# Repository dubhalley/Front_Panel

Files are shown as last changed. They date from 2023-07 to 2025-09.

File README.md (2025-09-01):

# Front_Panel

**Here an example of a design on Inkscape**

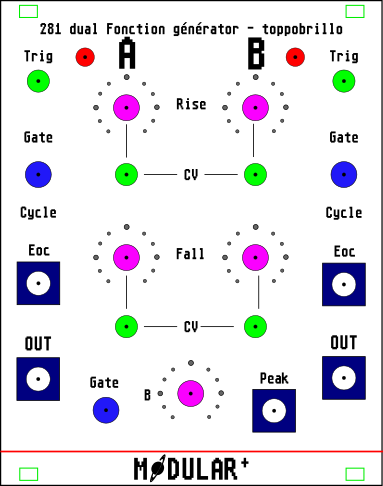
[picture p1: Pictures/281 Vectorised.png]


**Here the result after laserCutting and coloring fonts with white paint**

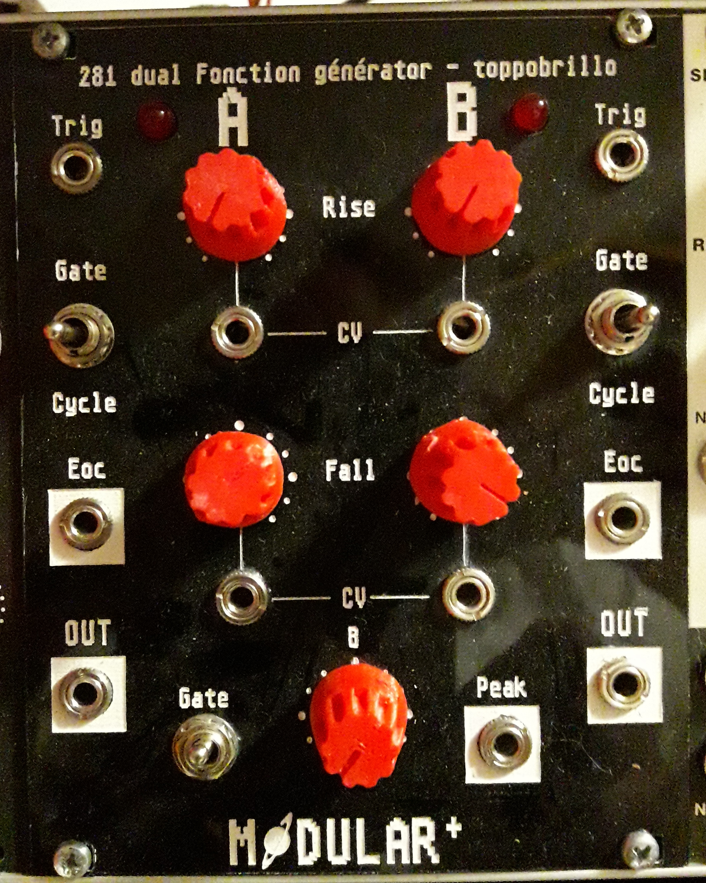
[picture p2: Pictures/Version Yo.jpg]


## 1 - Design software

**FREECAD**

Freecad is a free 2D and 3D drawing software. : https://www.freecad.org/
It allowed me to draw the module's outer contour and fixing holes.

Then I insert it into Inkscape to add images and texts.
But, why don't I use Inkscape at the beginning for the module's outer contour and fixing holes ?

Quite simply because Freecad lets me set dimensional constraints.
The outside size can be defined very precisely, and the fixing holes can be placed at an exact distance from the edge.
And, even if I change the outside dimension, the position and size of the fixing holes will remain the same.

I made files with the current front panel sizes

You will find them in the 2D files folder.

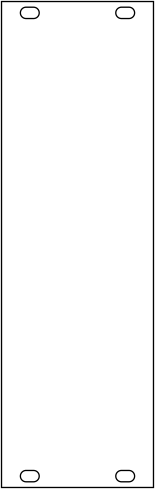
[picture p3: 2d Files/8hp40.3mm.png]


**INKSCAPE**

Inkscape is a free 2D vectoriel drawing software. https://inkscape.org/
In Inkscape you can create a 2D vector design with easy and pretty image and text insertion with also some tool to align holes of defined diameters for knob, switch, jacks, leds ... 
You can play with fonts, pictures and much more... :)

Here one of my design, you'll find the .svg on 2D files folder

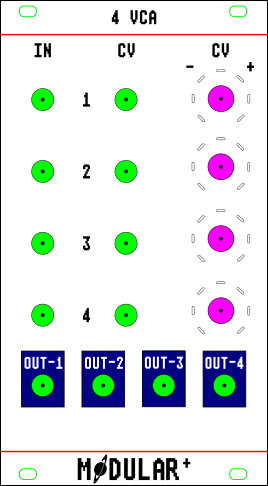
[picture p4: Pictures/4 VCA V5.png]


There is also my generic page with all the necessary components (Jacks, Pots, switchs...)

You'll find them in .svg format the 2D files folder.

**KICAD**

Kicad is a free creating pcb software. https://www.kicad.org/
It is common to obtain front panels using this software.

You have to insert the svg file in Kicad, and define each drawing or writing on a layer of the PCB.

I wanted to make a documentation, but during my reading, I found some resources on synth front panel manufacturing that make me think I probably couldn't do better... :)

https://arx.wtf/blog/1-front-panels-tips

https://www.youtube.com/watch?v=m__D1doHVVk

## 2 - Fabrication

To obtain the next front panels you'll need a lasercutter. Like 3d printer you can find it in a fablab.

**Lasercut PMMA**

An example of lasercutted Pmma or plexiglas



1 - Rendering after laser cutting

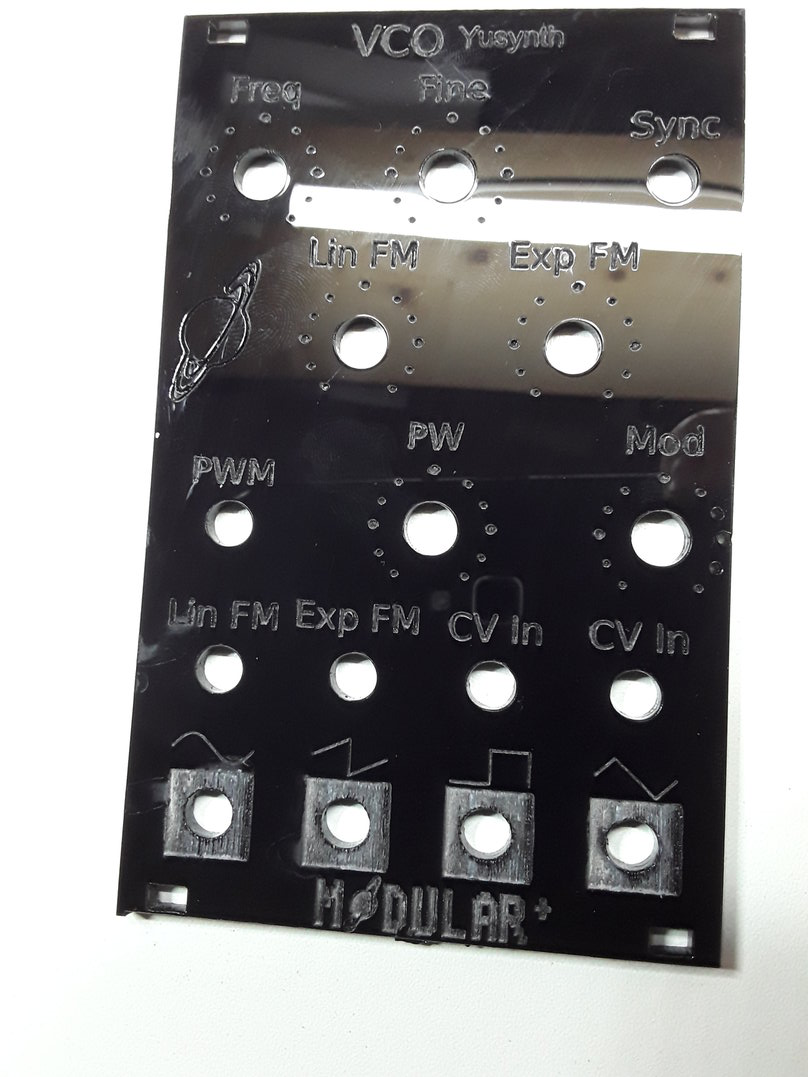
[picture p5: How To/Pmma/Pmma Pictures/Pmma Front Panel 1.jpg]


2 - Paint for inking writings and drawings

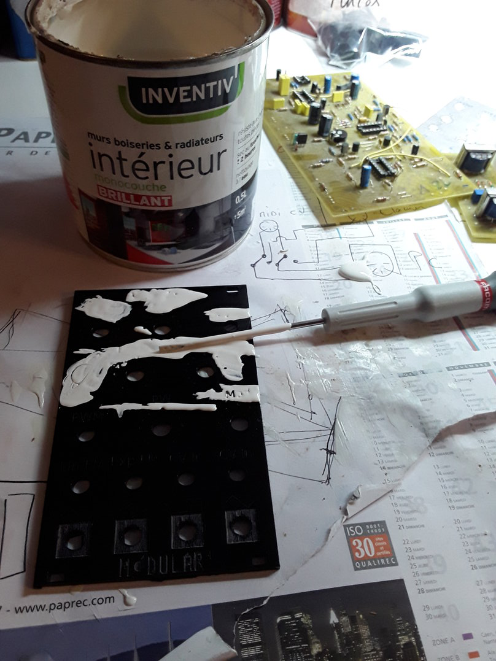
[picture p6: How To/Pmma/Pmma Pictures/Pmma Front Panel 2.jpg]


3 - A tiling scraper to spread it all out so that it fits into the grooves.

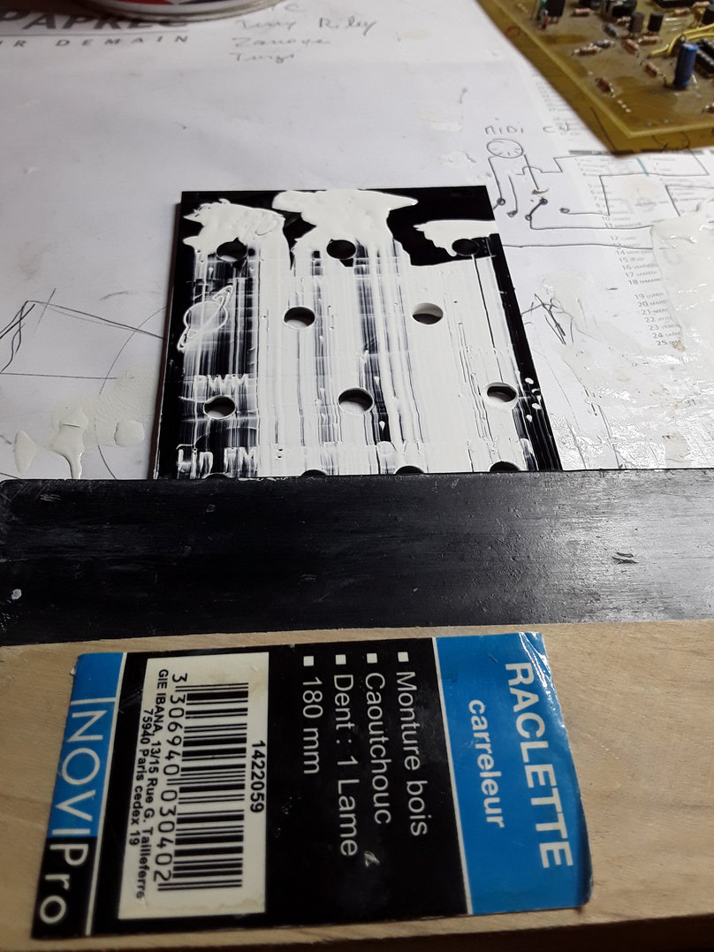
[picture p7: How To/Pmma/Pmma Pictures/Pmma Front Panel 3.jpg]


4 - Leave to dry

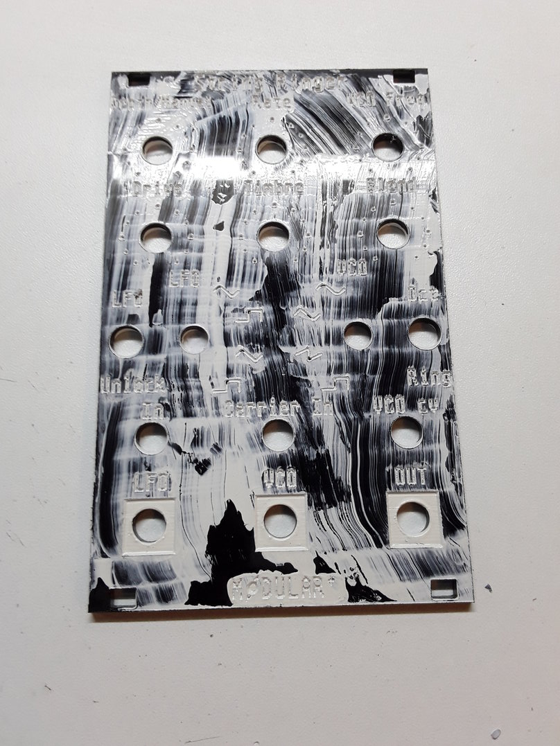
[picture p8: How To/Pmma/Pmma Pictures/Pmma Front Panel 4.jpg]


5 - Take a wet cloth and rub to remove any paint that's not in the right place.

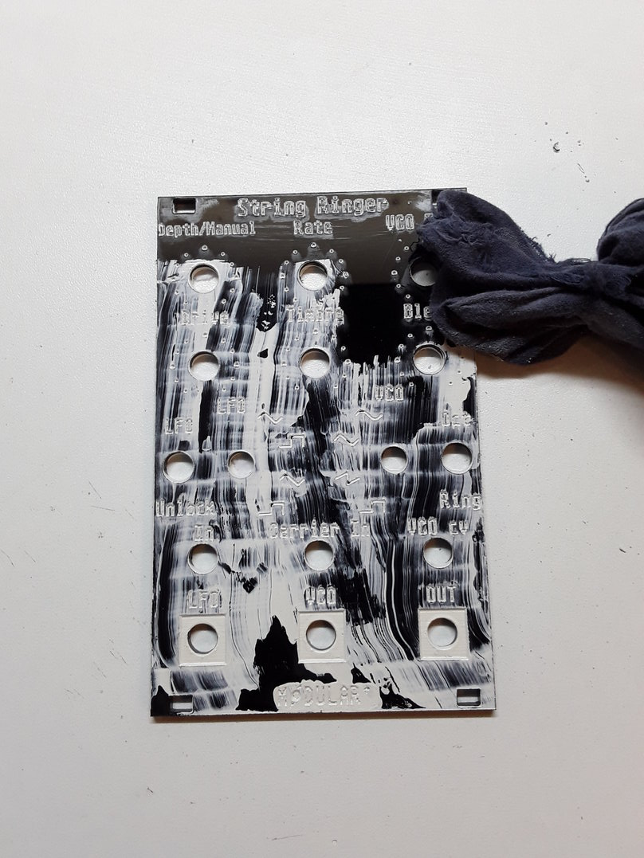
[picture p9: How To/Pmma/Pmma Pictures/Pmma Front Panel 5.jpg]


6 - Here's how it looks, when it's all finished (I'm not very fussy) we can do better ...

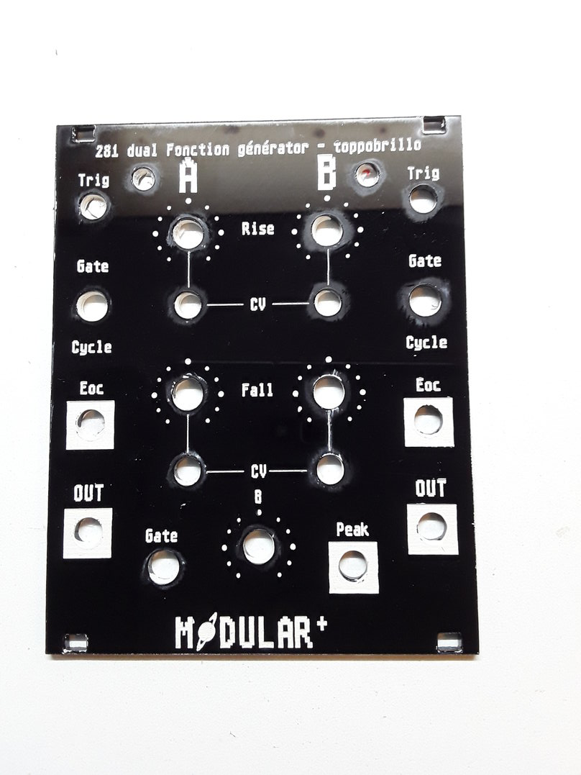
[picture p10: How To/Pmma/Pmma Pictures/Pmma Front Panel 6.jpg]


7 - The front panel with parts

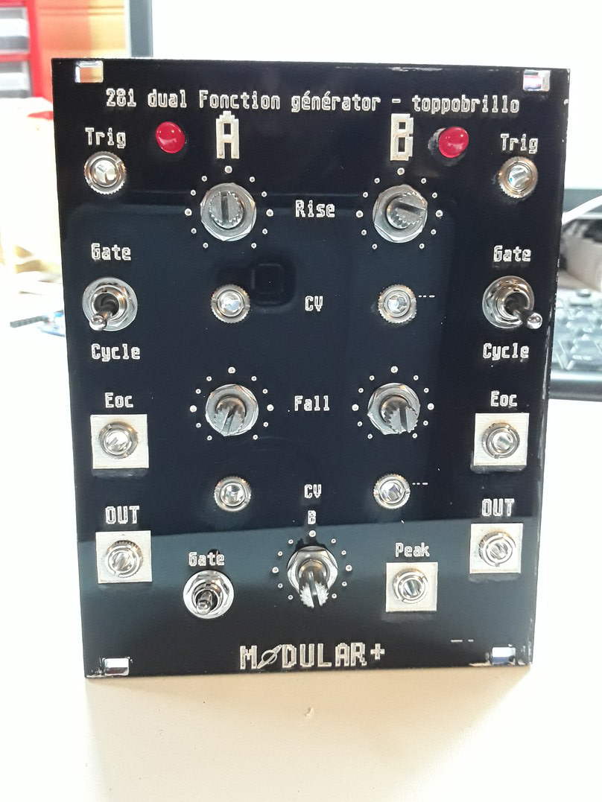
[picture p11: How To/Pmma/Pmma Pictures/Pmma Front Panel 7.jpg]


8 - It's all over

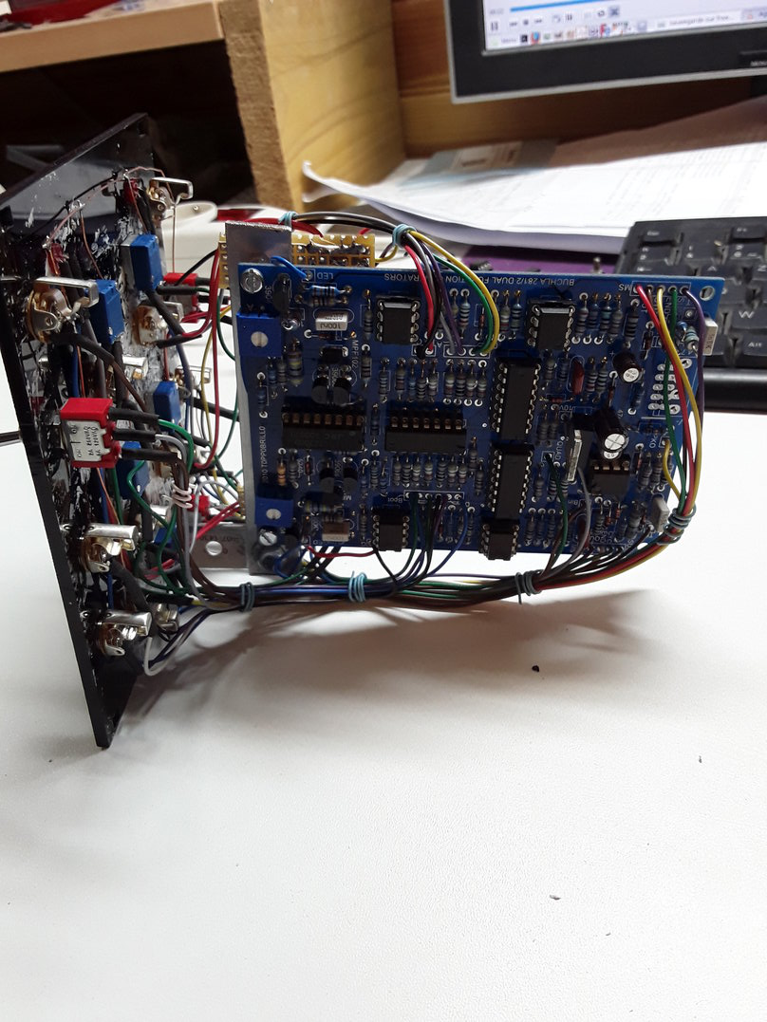
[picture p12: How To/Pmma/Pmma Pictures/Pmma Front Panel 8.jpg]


**Lasercut WOOD**

Poplar plywood 3mm

There's less work after cutting for poplar plywood, as the engraving provides enough contrast to distinguish the writing and images.



**Lasergraving Dibond**

3mm dibond = Dibond® is an aluminum composite material (ACM). It is comprised of two pre-painted sheets of . 012″ (. 30mm) aluminum with a solid polyethylene core.

Most easy-to-find machines cannot engrave in aluminum.
But aluminum is painted, so engraving works in place of cutting.
However, you'll need to drill the holes with a drill press and cut the edge precisely.
But it's functional, quite pretty, and inexpensive, as sports clubs use this material for their advertising.
As their sponsors change, they no longer use the old panels...
On one side there's the advertising, on the other it's blank, ready to engrave, sometimes even with the protective layer still on :)



1 - Open your design in lightburn or other software to control the laser cutter, and choose what will be filled in (as if coloring the inside of a drawing) and what will be marked (as if drawing just the outline of the drawing).



2 - Engraving

I'm using an Atomstack X20 Pro



3 - Cleaning the engraving

To clean, I use toothpaste and a toothbrush, because it sands nicely without scratching too much.

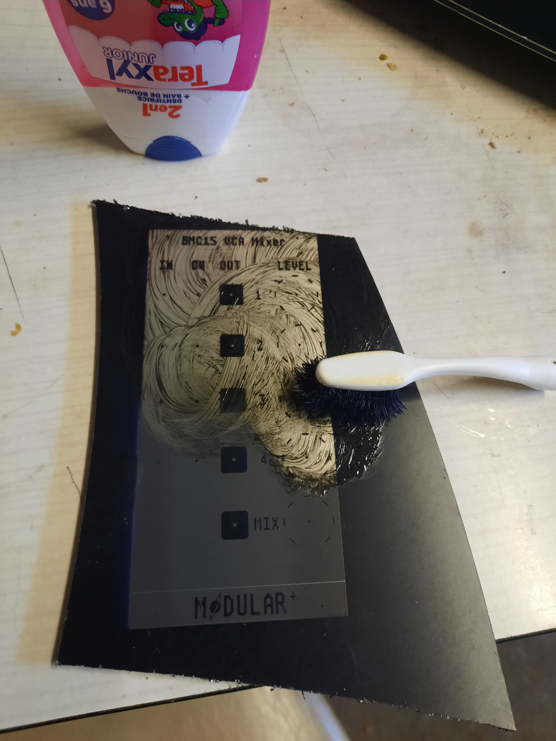
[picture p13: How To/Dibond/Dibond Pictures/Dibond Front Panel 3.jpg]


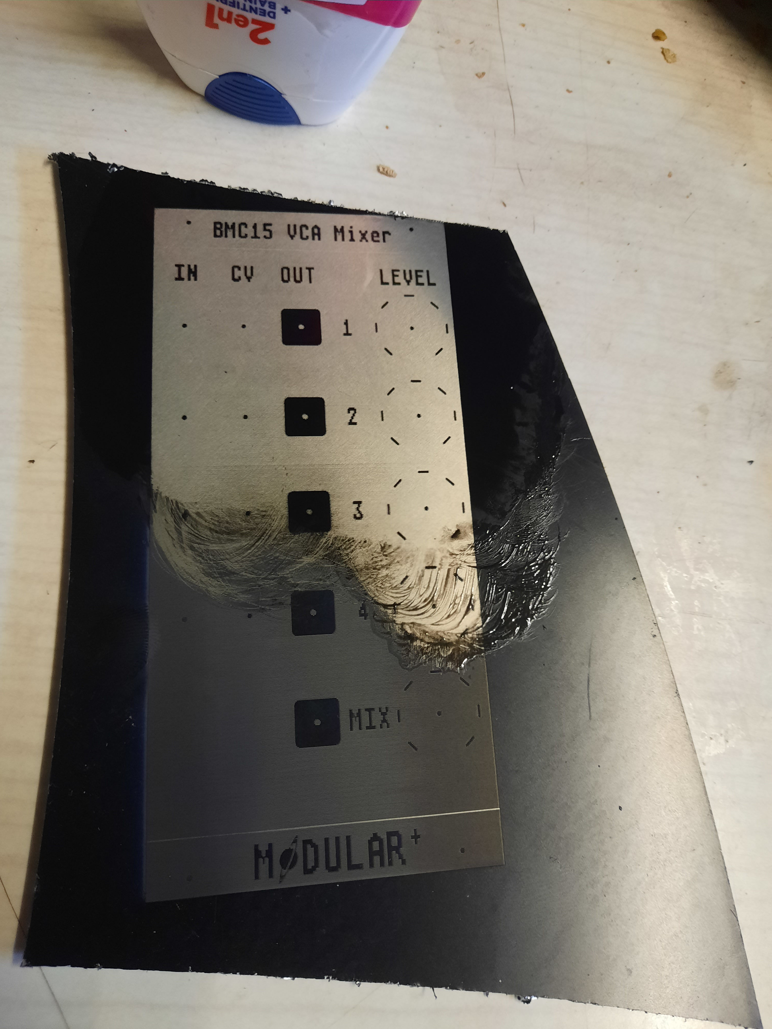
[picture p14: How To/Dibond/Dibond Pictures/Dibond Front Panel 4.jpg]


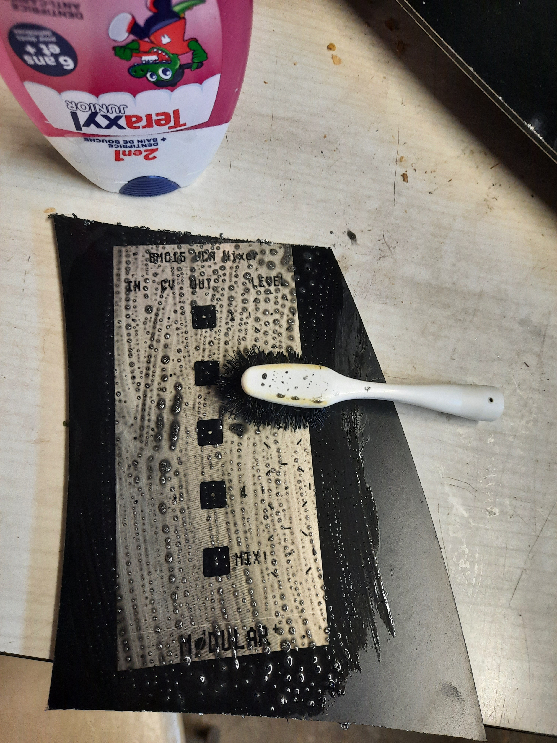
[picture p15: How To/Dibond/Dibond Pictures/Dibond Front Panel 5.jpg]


4 - Cut and file the edges

To cut the edges, I use a wooden wedge to guide the hacksaw blade.

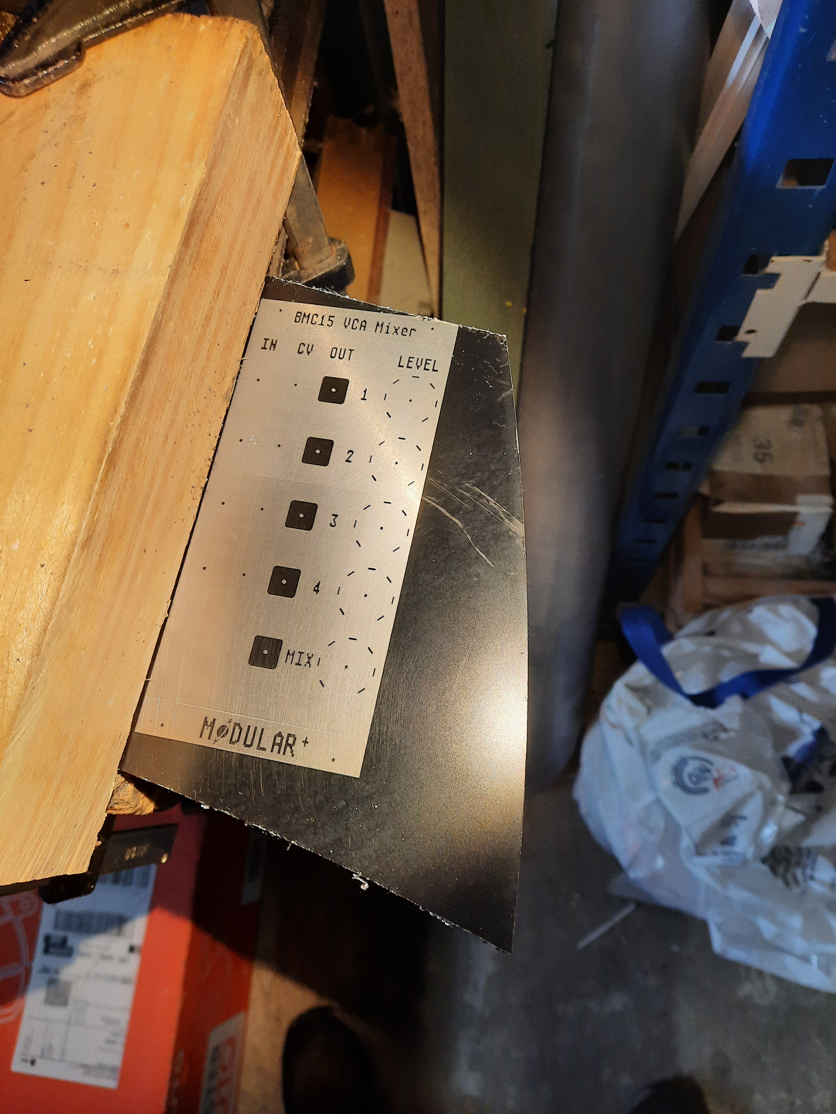
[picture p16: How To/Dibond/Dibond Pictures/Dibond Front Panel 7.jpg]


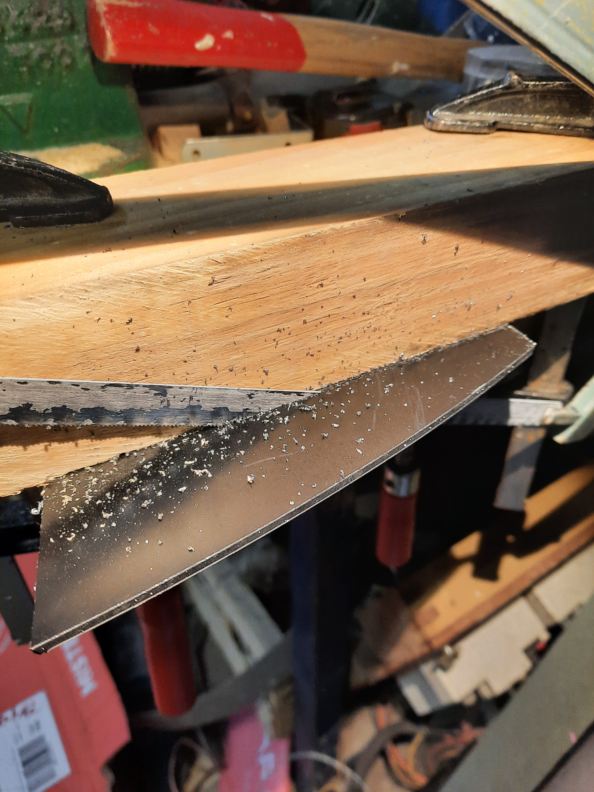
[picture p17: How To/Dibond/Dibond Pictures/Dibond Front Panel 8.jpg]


Edges need to be deburred to remove sharp edges

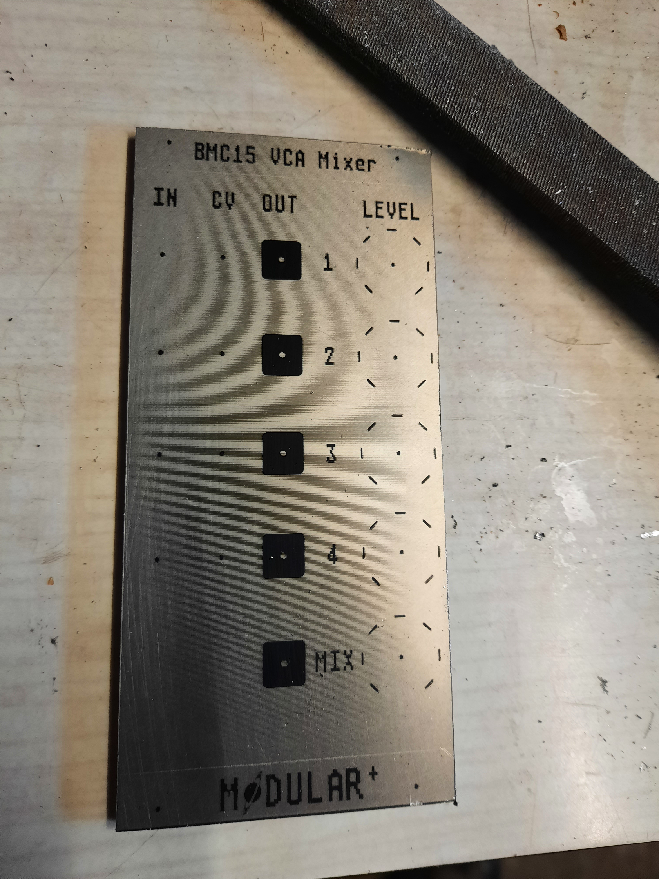
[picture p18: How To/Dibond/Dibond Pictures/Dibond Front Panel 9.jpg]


5 - Drill the holes

Make a mark with a punch, and drill the holes, start with a 3mm drill bit, then drill to 6mm for the jack and potentiometer etc.

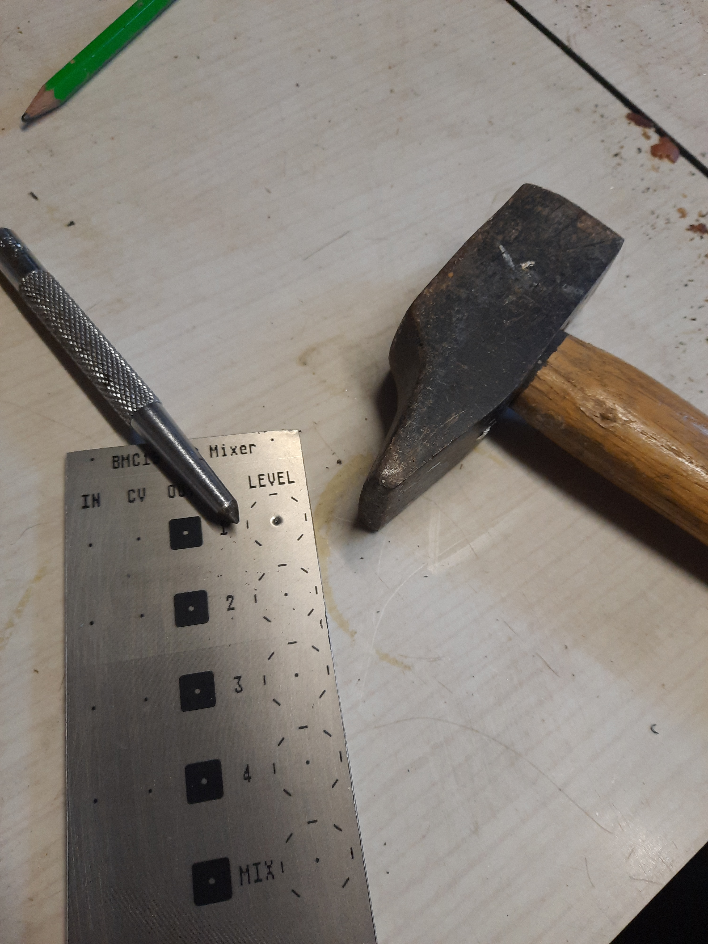
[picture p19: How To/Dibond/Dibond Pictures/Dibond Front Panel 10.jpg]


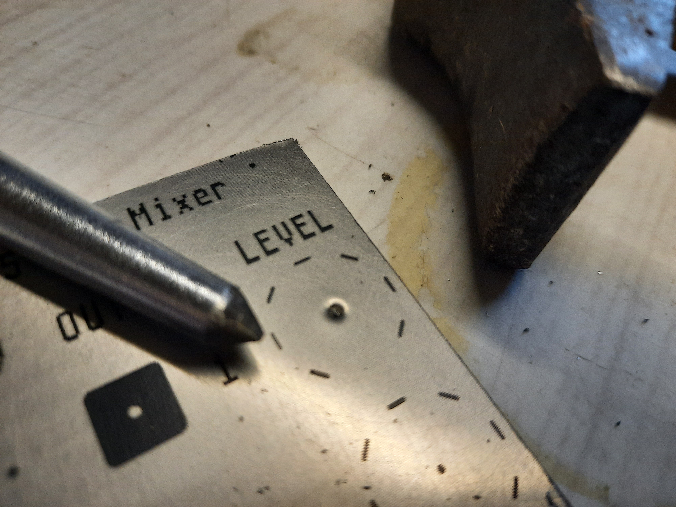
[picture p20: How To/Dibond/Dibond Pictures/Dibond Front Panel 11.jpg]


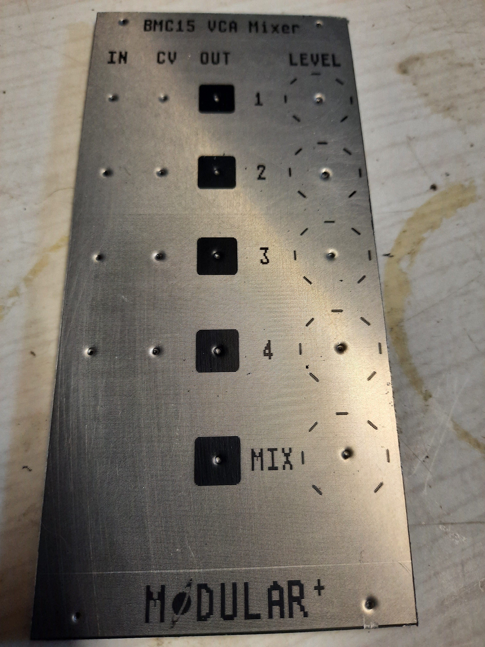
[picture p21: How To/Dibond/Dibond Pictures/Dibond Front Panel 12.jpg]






Deburr the edges of the hole to remove the cutting edge

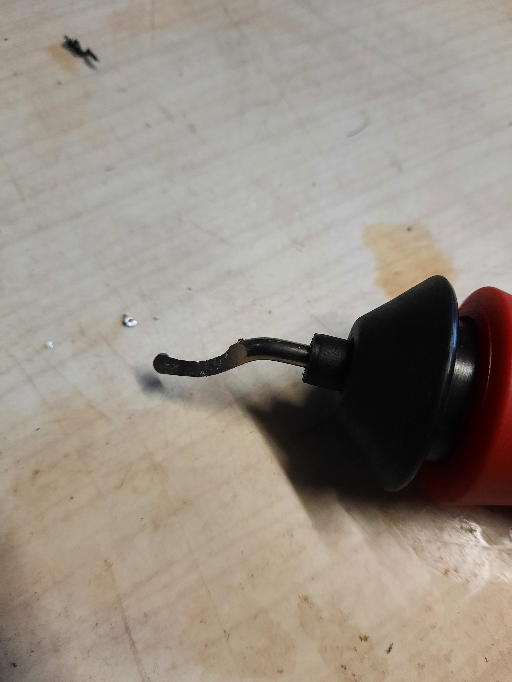
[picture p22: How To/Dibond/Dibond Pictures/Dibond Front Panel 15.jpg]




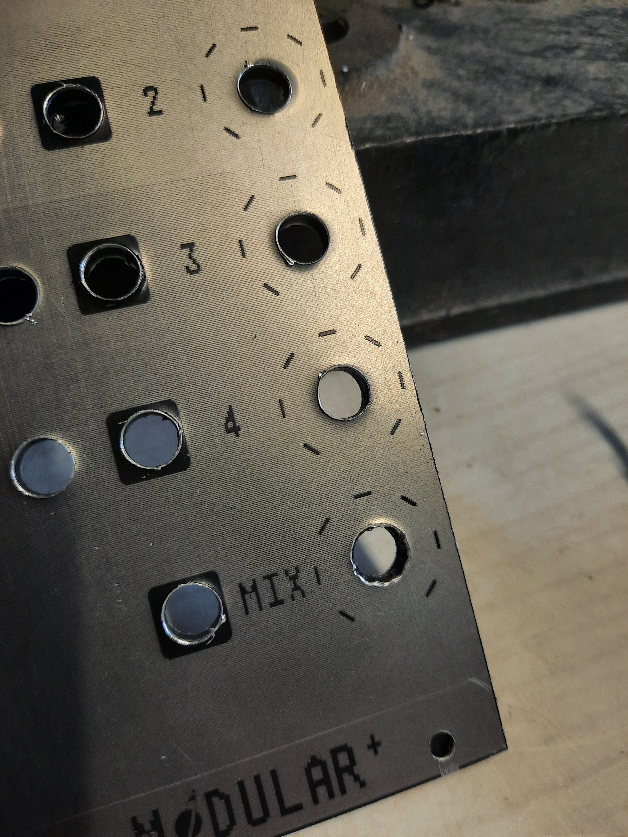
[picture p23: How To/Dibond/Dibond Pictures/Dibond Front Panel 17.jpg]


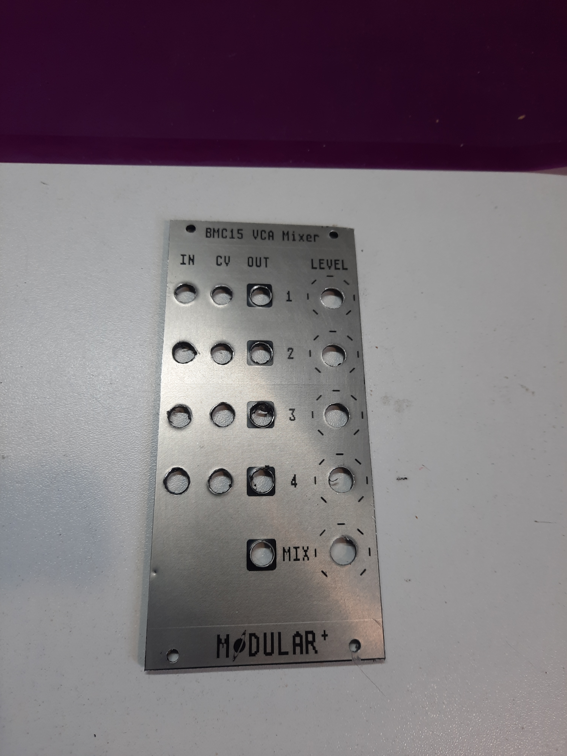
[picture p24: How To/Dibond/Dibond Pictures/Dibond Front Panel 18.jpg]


**Lasergraving Aluminium**

Most easy-to-find machines cannot engrave in aluminum. You need a fiber laser Cutter, and it's quite expensive ...
But aluminum can be painted, so engraving works in place of cutting.
But, you do need to protect the paint, however, as it will peel off. One solution is to apply a layer of transparent plastic adhesive.

However, you'll need to drill the holes with a drill press and cut the edge precisely.



**Etch PCB**

To obtain this quality of fabrication - Not the design :) - you'll need to send GERBER files to a PCB supplyer. 

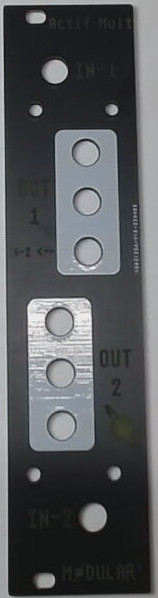
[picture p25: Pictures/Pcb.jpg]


**3d print**

It's also possible to 3d print the front panel. 
I use 3d panel only for blank panel

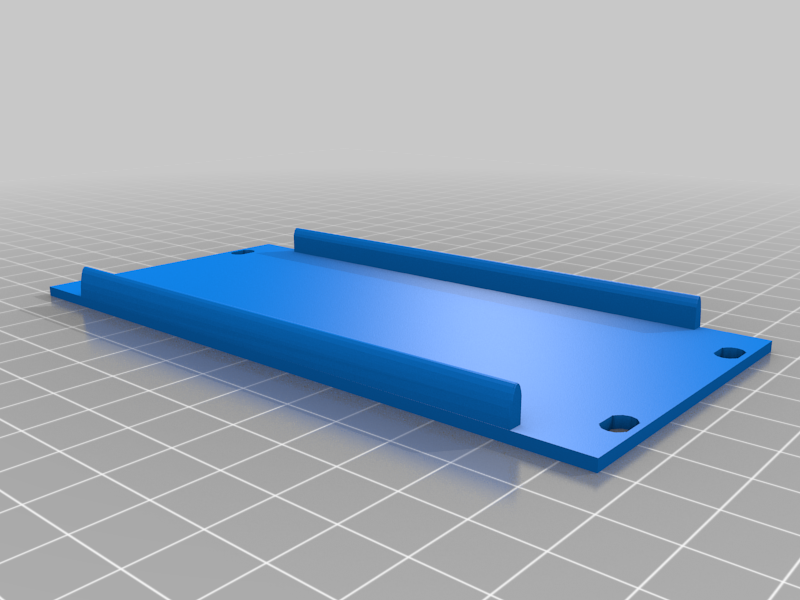
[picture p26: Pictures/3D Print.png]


This website allows you to download and print eurorack parts. 

https://www.thingiverse.com/thing:1850240

https://www.thingiverse.com/search?q=eurorack&page=1&type=things&sort=relevant

## 3 - More resources on creating front panel

SDIY.info wiki 

* https://sdiy.info/wiki/Eurorack_panel_components

Synth Panel Designer : An Inkscape add ons to do your own front panel

* https://synthpanels.design/

ModWiggler forum :

* https://modwiggler.com/forum/viewtopic.php?t=282087&sid=c586f268479aaaf0befdb3511445877c#top

* https://modwiggler.com/forum/viewtopic.php?t=235049

* https://modwiggler.com/forum/viewtopic.php?t=180347&start=400

Horizontal Pitch : knob scales

* https://www.horizontalpitch.com/2023/11/design-clipboard-knob-scales/

A small table saw build in PVC, to cut the edges

* https://www.youtube.com/watch?v=B5hse3_FMNY

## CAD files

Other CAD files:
2d Files/4hp.FCStd

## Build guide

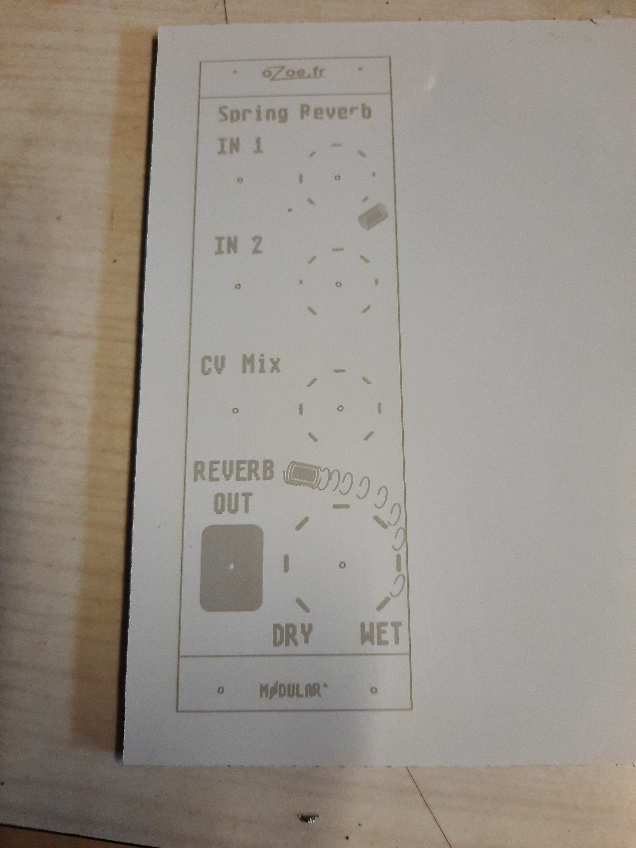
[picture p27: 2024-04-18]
How To/Dibond/Dibond Pictures/Dibond Front Panel 6.jpg

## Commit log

2023-07-31 Add files via upload
    add toppobrillo 281 Front plate
2024-03-29 improve content
    [4hp.FCStd]
2024-04-18 add How to Pmma
    [281.dxf]
2024-04-18 fix typing errors
    [281.dxf]
2025-07-06 update pcb design
